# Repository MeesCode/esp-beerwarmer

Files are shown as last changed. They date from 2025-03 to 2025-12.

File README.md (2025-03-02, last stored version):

# ESP32-H2 Demo Zigbee Device

This project is a demo Zigbee device based on the ESP32-H2 / ESP32-C6

## Features

- [x] DHT22 temperature and humidity sensor
- [x] Binary switch
- [x] Binary input

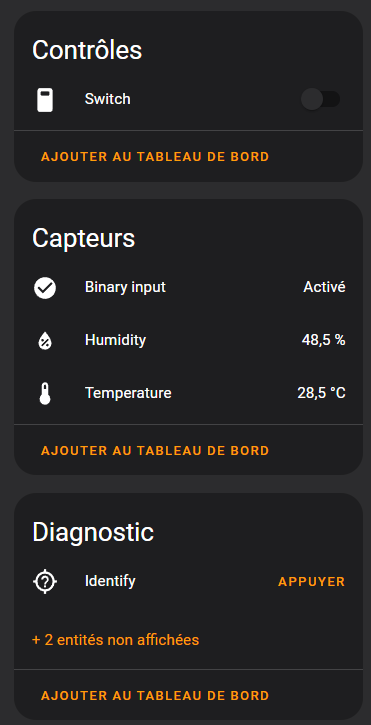
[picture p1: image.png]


## Hardware

- [ESP32-H2](https://www.espressif.com/en/products/socs/h2/overview)

## GPIO

| GPIO | Function |
| --- | --- |
| GPIO8  | DHT22 data |
| GPIO0  | Binary output (LED) |
| GPIO12 | Binary input (Button) |

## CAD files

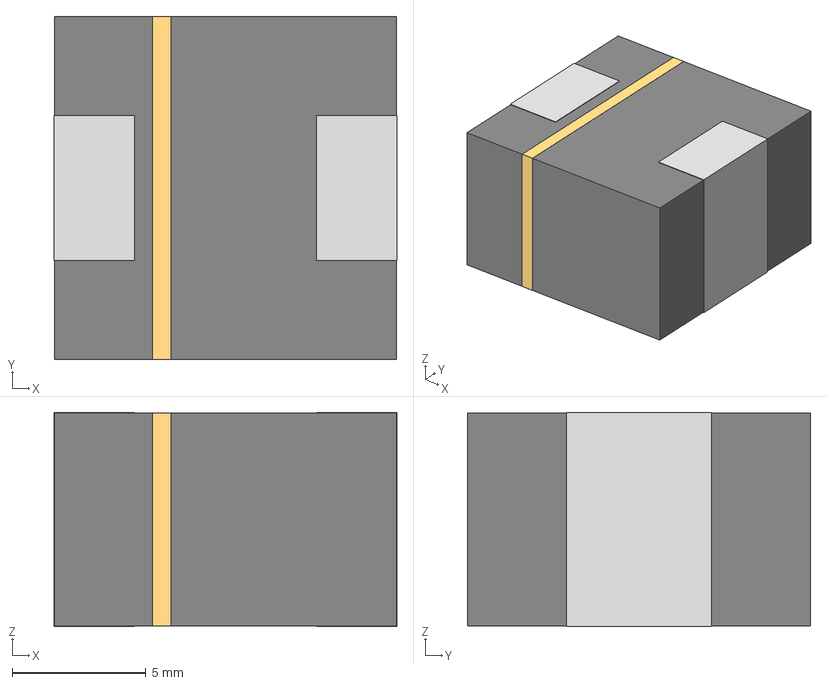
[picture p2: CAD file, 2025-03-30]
beer-warmer-schematics/3d models/IND_BOURNS_SRR1280.step
12.8 x 12.8 x 8.00 mm

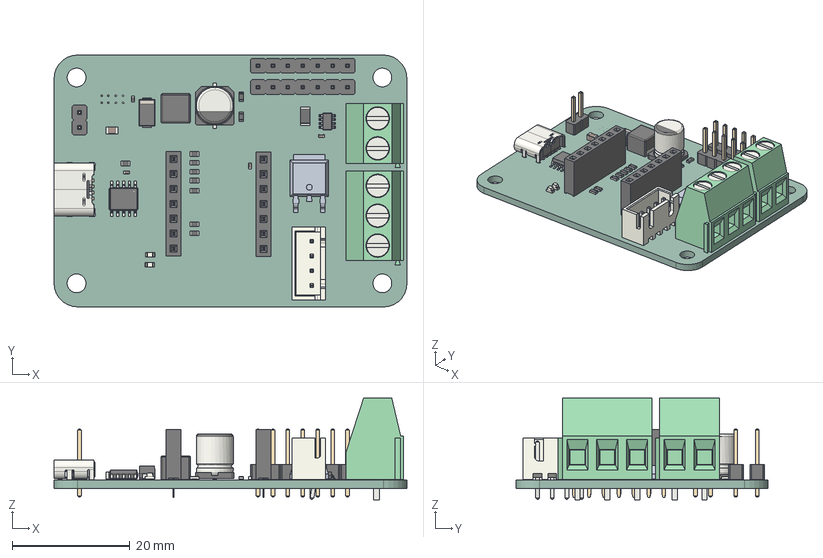
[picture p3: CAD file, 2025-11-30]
beer-warmer-schematics/beer-warmer-schematics.step
60.0 x 42.8 x 17.3 mm
C_0402_1005Metric x 4
LED_0603_1608Metric x 2
R_0603_1608Metric x 10
PinHeader_1x07_P2.54mm_Vertical x 2
R_1206_3216Metric
JST_XH_B4B-XH-A_1x04_P2.50mm_Vertical
TerminalBlock_Phoenix_MKDS-1,5-2-5.08_1x02_P5.08mm_Horizontal
beer-warmer-schematics 1.9.1
USB_C_Receptacle_GCT_USB4125-xx-x_6P_TopMnt_Horizontal
SOT-23-8
CP_Elec_6.3x7.7
PinHeader_1x02_P2.54mm_Vertical
C_0805_2012Metric
L_Changjiang_FNR5040S
D_SMA
TerminalBlock_Phoenix_MKDS-1,5-3-5.08_1x03_P5.08mm_Horizontal
PinSocket_1x07_P2.54mm_Vertical x 2
SSOP-10-1EP_3.9x4.9mm_P1mm_EP2.1x3.3mm
beer-warmer-schematics_PCB

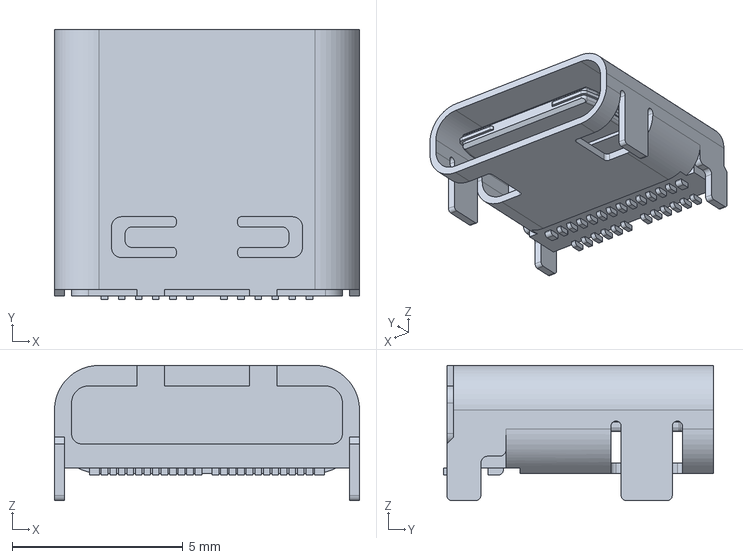
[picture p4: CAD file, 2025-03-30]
beer-warmer-schematics/3d models/1054500101.stp
8.94 x 7.90 x 3.96 mm

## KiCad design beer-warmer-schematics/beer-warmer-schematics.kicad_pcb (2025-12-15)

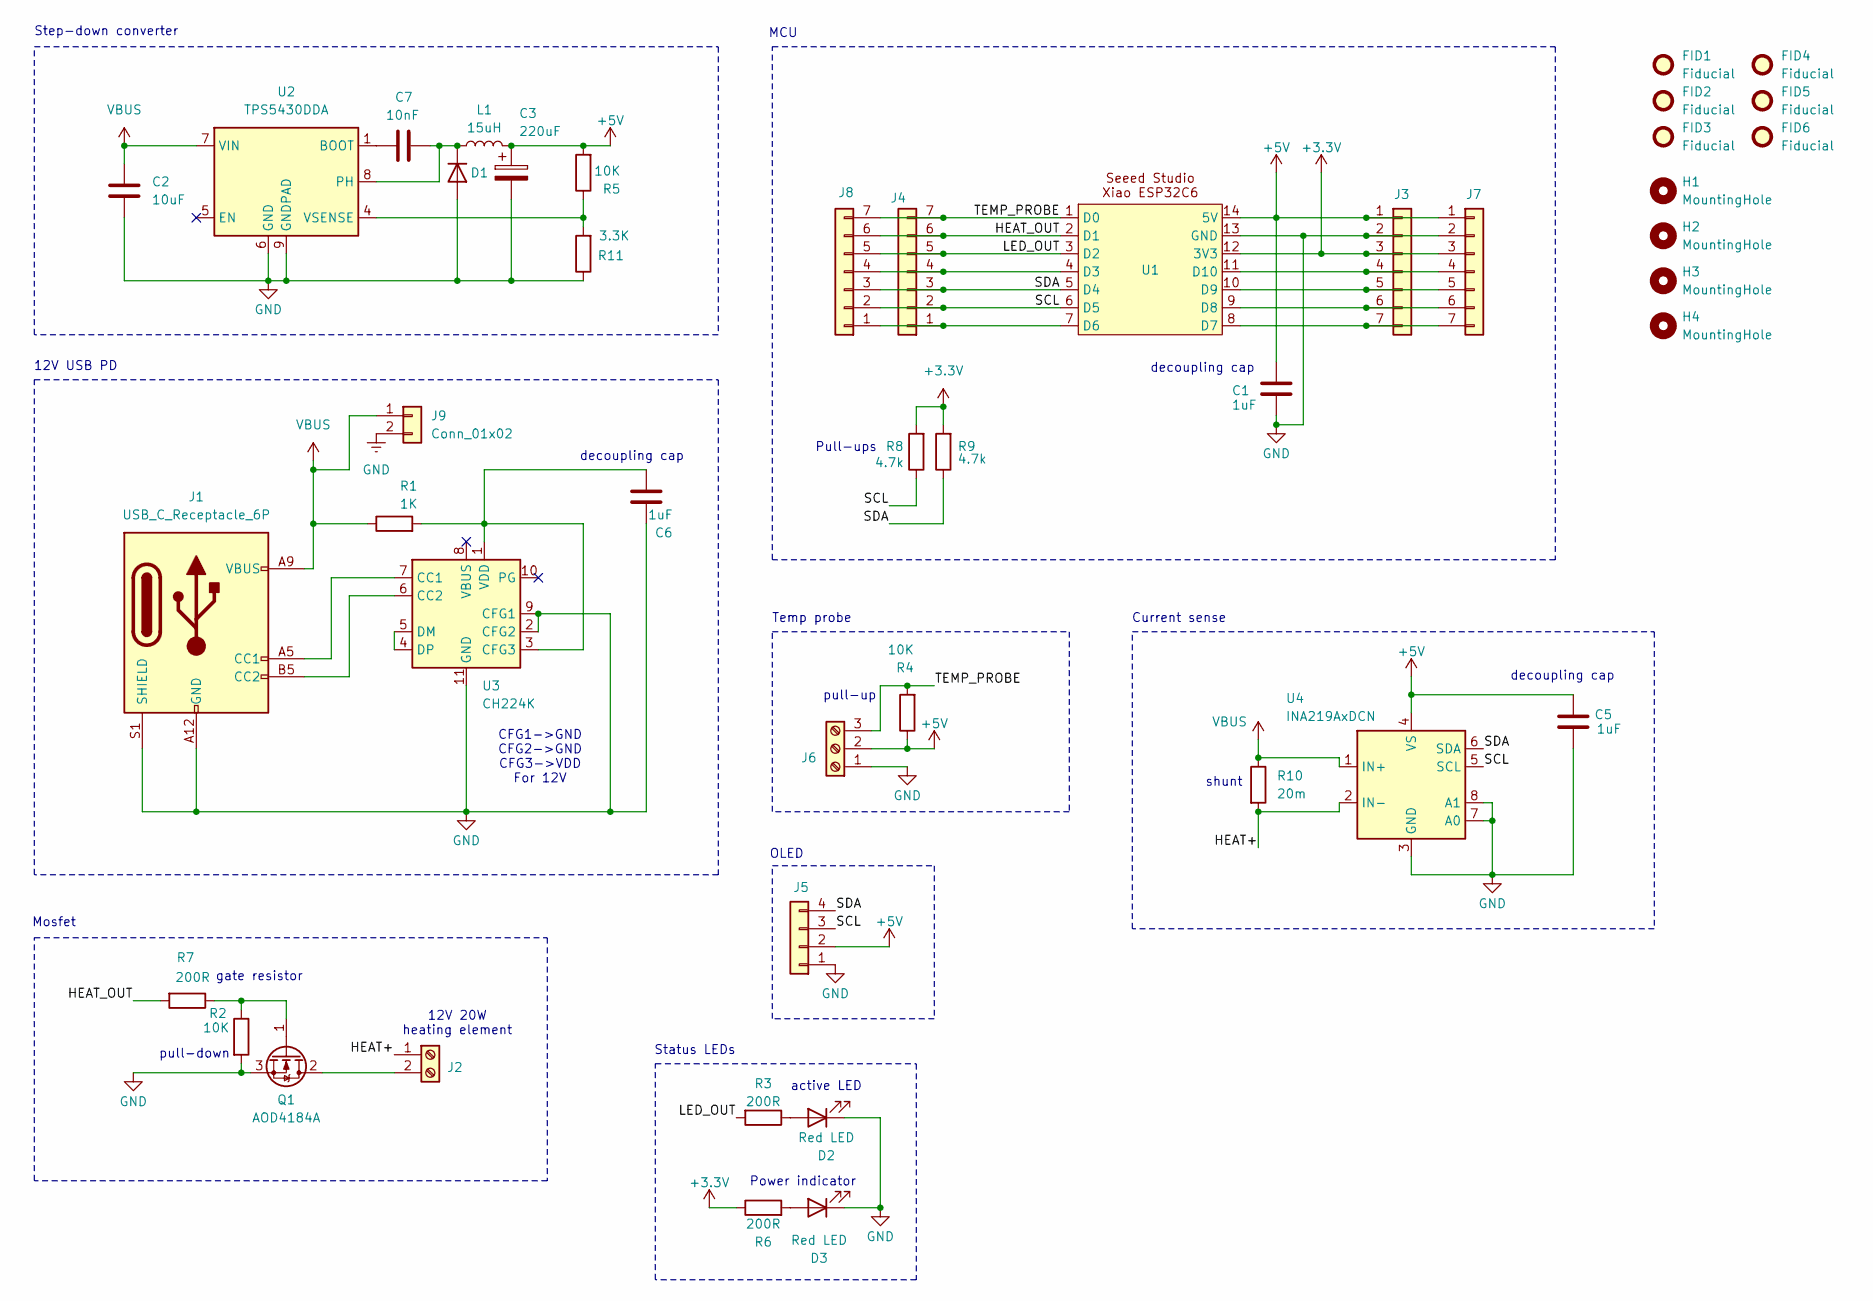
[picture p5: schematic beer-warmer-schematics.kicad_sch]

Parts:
C1, C5, C6: 1uF; C_0402_1005Metric; LCSC C52923
C2: 10uF; C_0805_2012Metric; LCSC C15850
C3: 220uF; CP_Elec_6.3x7.7; LCSC C3342
C7: 10nF; C_0402_1005Metric; LCSC C1524
D1: D; D_SMA; Manufacturer # B530C-13-F; LCSC C64982
D2, D3: Red LED; LED_0603_1608Metric; LCSC C2286
FID1, FID2, FID3, FID4, FID5, FID6: Fiducial; Fiducial_0.5mm_Mask1.5mm
H1, H2, H3, H4: MountingHole; MountingHole_3.2mm_M3_DIN965_Pad
J1: USB_C_Receptacle_6P; USB_C_Receptacle_GCT_USB4125-xx-x_6P_TopMnt_Horizontal; Manufacturer # 1054500101; LCSC C456012
J2: Screw_Terminal_01x02; TerminalBlock_Phoenix_MKDS-1,5-2-5.08_1x02_P5.08mm_Horizont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; LCSC C8465
J3, J4: Conn_01x07_Socket; PinSocket_1x07_P2.54mm_Vertical; LCSC C2932672
J5: Conn_01x04_Pin; JST_XH_B4B-XH-A_1x04_P2.50mm_Vertical; LCSC C594232
J6: Screw_Terminal_01x03; TerminalBlock_Phoenix_MKDS-1,5-3-5.08_1x03_P5.08mm_Horizont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; LCSC C72334
J7, J8: Conn_01x07_Socket; PinHeader_1x07_P2.54mm_Vertical; LCSC C2932672
J9: Conn_01x02; PinHeader_1x02_P2.54mm_Vertical
L1: 15uH; L_Changjiang_FNR5040S; LCSC C167969
Q1: AOD4184A; TO-252-2; LCSC C99124
R1: 1K; R_0603_1608Metric; LCSC C21190
R2, R4, R5: 10K; R_0603_1608Metric; LCSC C15401
R3, R6, R7: 200R; R_0603_1608Metric; LCSC C22962
R8, R9: 4.7k; R_0603_1608Metric; LCSC C23162
R10: 20m; R_1206_3216Metric; LCSC C393094
R11: 3.3K; R_0603_1608Metric; LCSC C22978
U1: XIAO-ESP32C6-DIP
U2: TPS5430DDA; TI_SO-PowerPAD-8_ThermalVias; LCSC C9864
U3: CH224K; SSOP-10-1EP_3.9x4.9mm_P1mm_EP2.1x3.3mm; LCSC C970725
U4: INA219AxDCN; SOT-23-8; LCSC C87469

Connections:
+3.3V: J3.3, J7.3, R6.1, R8.2, R9.2, U1.12 (3V3)
+5V: C1.1, C3.1, C5.2, J3.1, J5.2, J6.2, J7.1, L1.2, R4.1, R5.2, U1.14 (5V), U4.4 (VS); also elsewhere on the board
/<NO NET>: J4.4, J8.4, U1.4 (D3)
/HEAT+: J2.1, R10.2, U4.2 (IN-)
/HEAT_OUT: J4.6, J8.6, R7.2, U1.2 (D1)
/LED_OUT: J4.5, J8.5, R3.2, U1.3 (D2)
/SCL: J4.2, J5.3, J8.2, R8.1, U1.6 (D5), U4.5 (SCL)
/SDA: J4.3, J5.4, J8.3, R9.1, U1.5 (D4), U4.6 (SDA)
/TEMP_PROBE: J4.7, J6.3, J8.7, R4.2, U1.1 (D0)
GND: C1.2, C2.2, C3.2, C5.1, C6.1, D1.2 (A), D2.1 (K), D3.1 (K), J1.A12 (GND), J1.B12 (GND), J1.S1 (SHIELD), J3.2, J5.1, J6.1, J7.2, J9.2, Q1.3 (S), R2.2, R11.1, U1.13 (GND), U2.6 (GND), U2.9 (GNDPAD), U3.2 (CFG2), U3.9 (CFG1), U3.11 (GND), U4.3 (GND), U4.7 (A0), U4.8 (A1)
unnamed: C7.1, D1.1 (K), L1.1, U2.8 (PH)
unnamed: D2.2 (A), R3.1
unnamed: D3.2 (A), R6.2
unnamed: J1.A5 (CC1), U3.7 (CC1)
unnamed: J1.B5 (CC2), U3.6 (CC2)
unnamed: J2.2, Q1.2 (D)
unnamed: J3.4, J7.4, U1.11 (D10)
unnamed: J3.5, J7.5, U1.10 (D9)
unnamed: J3.6, J7.6, U1.9 (D8)
unnamed: J3.7, J7.7, U1.8 (D7)
unnamed: J4.1, J8.1, U1.7 (D6)
unnamed: Q1.1 (G), R2.1, R7.1
unnamed: C7.2, U2.1 (BOOT)
unnamed: R5.1, R11.2, U2.4 (VSENSE)
unnamed: C6.2, R1.2, U3.1 (VDD), U3.3 (CFG3)
unnamed: U3.4 (DP), U3.5 (DM)
VBUS: C2.1, J1.A9 (VBUS), J1.B9 (VBUS), J9.1, R1.1, R10.1, U2.7 (VIN), U4.1 (IN+)

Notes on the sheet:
decoupling cap
12V 20W heating element
12V USB PD
Status LEDs
Current sense
OLED
pull-up
Power indicator
gate resistor
shunt
active LED
Step-down converter
Mosfet
Pull-ups
pull-down
CFG1->GND CFG2->GND CFG3->VDD For 12V
MCU
Temp probe

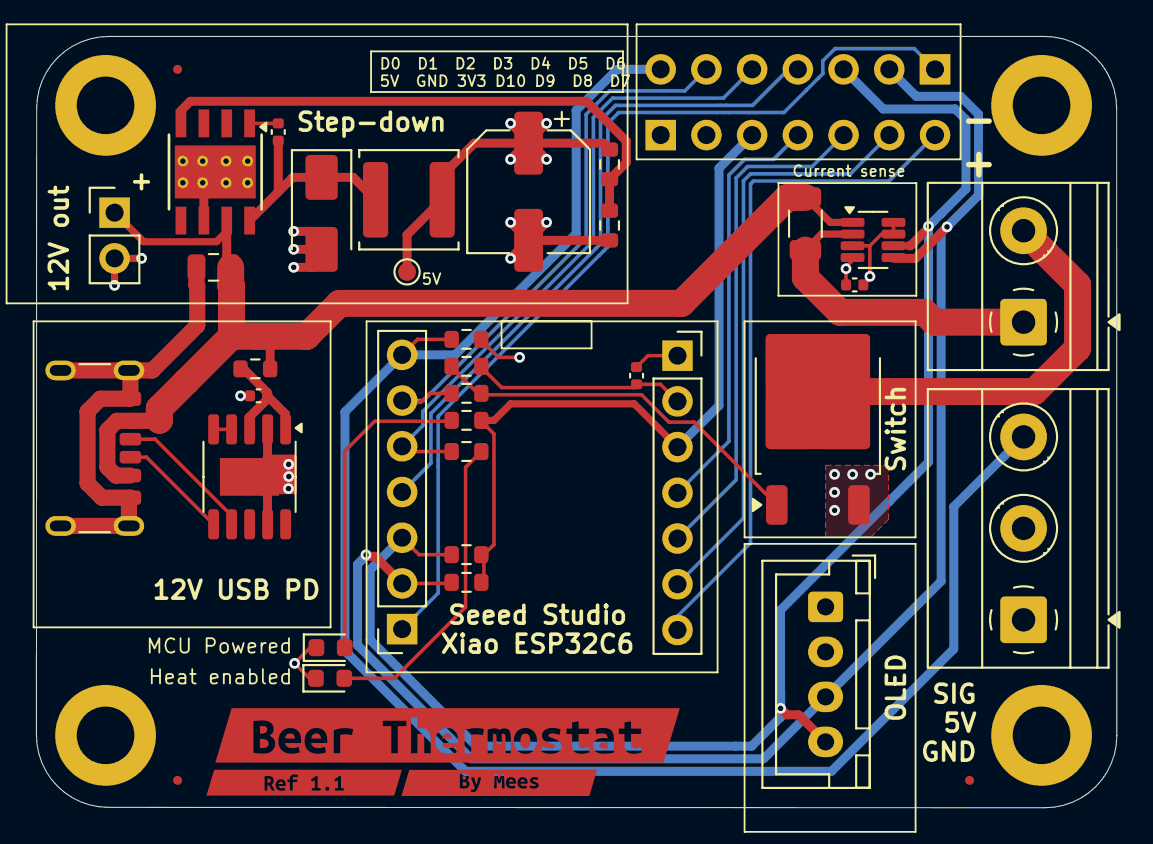
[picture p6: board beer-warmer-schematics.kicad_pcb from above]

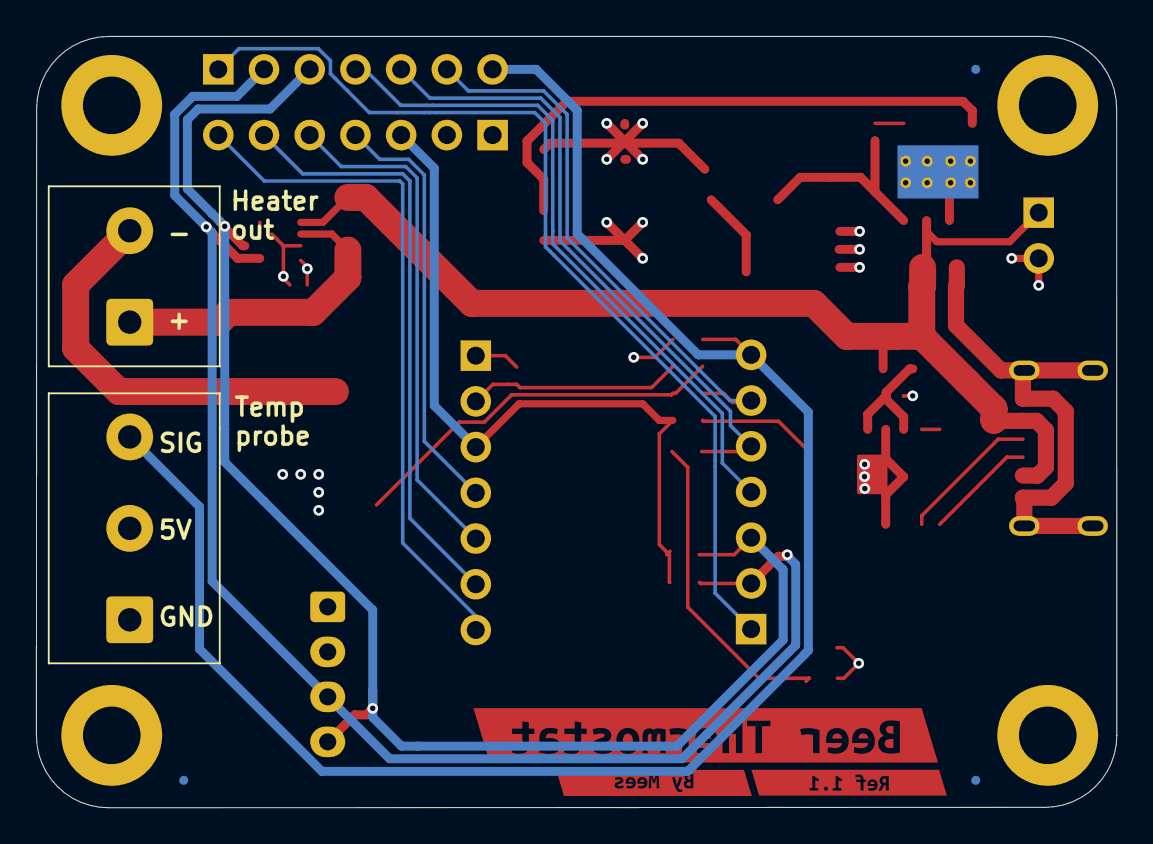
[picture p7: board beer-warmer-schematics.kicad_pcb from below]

Board: 4 copper layers, 60.0 x 42.8 mm, 48 parts (3 on the bottom side), 27 nets.

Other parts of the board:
TP2: TestPoint; TestPoint_Pad_D1.0mm
kibuzzard-67EFB7C2: G***; kibuzzard-67EFB7C2
kibuzzard-67EFB7D4: G***; kibuzzard-67EFB7D4
kibuzzard-693FEE7D: G***; kibuzzard-693FEE7D

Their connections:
+5V: TP2.1; also elsewhere on the board

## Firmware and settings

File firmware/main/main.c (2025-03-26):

#include "nvs_flash.h"
#include "esp_check.h"
#include "esp_log.h"
#include "freertos/FreeRTOS.h"
#include "freertos/task.h"
#include "ha/esp_zigbee_ha_standard.h"
#include "main.h"
#include "string.h"
#include "driver/gpio.h"
#include "temp_sensor.h"

#include "driver/i2c_master.h"
#include "esp_lcd_panel_io.h"
#include "esp_lcd_panel_vendor.h"
#include "esp_lcd_panel_ops.h"

#include "oled_gfx.h"

#define HEATER_PIN GPIO_NUM_1

static const char *TAG = "MAIN";
bool zb_connected = false;
bool switch_state = true;

const float target_temp = 22.0;
const float temp_offset = 0.1;

float temps[128] = {-1.0f};
int temp_index = 0;

#define DEFINE_PSTRING(var, str)   \
    const struct                   \
    {                              \
        unsigned char len;         \
        char content[sizeof(str)]; \
    }(var) = {sizeof(str) - 1, (str)}


void report_output_binary_sensor(uint16_t value)
{
    esp_zb_zcl_set_attribute_val(
        HA_ESP_ENDPOINT,
        ESP_ZB_ZCL_CLUSTER_ID_BINARY_INPUT, 
        ESP_ZB_ZCL_CLUSTER_SERVER_ROLE, 
        ESP_ZB_ZCL_ATTR_BINARY_INPUT_PRESENT_VALUE_ID, 
        &value, 
        false
    );
}

void report_temperature(float temp)
{
    uint16_t temp_zb = (uint16_t)(temp*100.);
    esp_zb_zcl_set_attribute_val(
        HA_ESP_ENDPOINT, 
        ESP_ZB_ZCL_CLUSTER_ID_TEMP_MEASUREMENT, 
        ESP_ZB_ZCL_CLUSTER_SERVER_ROLE, 
        ESP_ZB_ZCL_ATTR_TEMP_MEASUREMENT_VALUE_ID, 
        &temp_zb, 
        false
    );
}

void draw_graph()
{
    gfx_clear_area(0, 32, 128, 32);
    float max_temp = 0;
    float min_temp = 100;
    for(int i = 0; i < 128; i++){
        if(temps[i] > max_temp && temps[i] >= 0) max_temp = temps[i] + 0.5;
        if(temps[i] < min_temp && temps[i] >= 0) min_temp = temps[i] - 0.5;
    }

    float pxpt = (32.0) / (max_temp - min_temp);
    ESP_LOGI(TAG, "index: %d, max_temp: %f, min_temp: %f", temp_index, max_temp, min_temp);

    int prev_y = -1.0f;
    for(int i = 0; i < 128; i++){
        int index = (temp_index + i + 1) % 128;

        if(temps[index] < 0) continue;
        int y = pxpt * (temps[index] - min_temp);

        if(prev_y < 0){
            gfx_set_pixel(i, 64 - y);
        } else if(y > prev_y){
            gfx_fill_area(i, 64 - y, 1, y - prev_y);
        } else if(y < prev_y){
            gfx_fill_area(i, 64 - prev_y, 1, prev_y - y);
        } else {
            gfx_set_pixel(i, 64 - y);
        }

        prev_y = y;
    }
    
}

static void temp_task(void *pvParameters)
{
    for(;;){
        vTaskDelay(100 / portTICK_PERIOD_MS);

        float temp = get_temp();

        char temp_str[10];
        sprintf(temp_str, "%.2f C ", temp);
        gfx_draw_text(0, 10, temp_str);

        temps[temp_index] = temp;

        draw_graph();
        if(zb_connected)
            report_temperature(temp);

        // roughly keep temp at 25c by turning on/off the heater
        if(temp < target_temp - temp_offset && switch_state){
            gpio_set_level(HEATER_PIN, 1);
            if(zb_connected)
                report_output_binary_sensor(1);
            gfx_draw_text(0, 20, "heat on ");
        } else if(temp > target_temp + temp_offset || !switch_state){
            gpio_set_level(HEATER_PIN, 0);
            if(zb_connected)
                report_output_binary_sensor(0);
            gfx_draw_text(0, 20, "heat off");
        }

        gfx_flush();
        temp_index = (temp_index + 1) % 128;
    }
}

static void bdb_start_top_level_commissioning_cb(uint8_t mode_mask)
{
    ESP_ERROR_CHECK(esp_zb_bdb_start_top_level_commissioning(mode_mask));
}

static esp_err_t zb_attribute_handler(const esp_zb_zcl_set_attr_value_message_t *message)
{
    esp_err_t ret = ESP_OK;
    ESP_RETURN_ON_FALSE(message, ESP_FAIL, TAG, "Empty message");
    ESP_RETURN_ON_FALSE(message->info.status == ESP_ZB_ZCL_STATUS_SUCCESS, ESP_ERR_INVALID_ARG, TAG, "Received message: error status(%d)",
                        message->info.status);
    ESP_LOGI(TAG, "Received message: endpoint(0x%x), cluster(0x%x), attribute(0x%x), data size(%d)", message->info.dst_endpoint, message->info.cluster, message->attribute.id, message->attribute.data.size);

    // handle light on/off
    if (message->info.dst_endpoint == HA_ESP_ENDPOINT){
        if (message->info.cluster == ESP_ZB_ZCL_CLUSTER_ID_ON_OFF){
            if (message->attribute.id == ESP_ZB_ZCL_ATTR_ON_OFF_ON_OFF_ID && message->attribute.data.type == ESP_ZB_ZCL_ATTR_TYPE_BOOL){
                switch_state = message->attribute.data.value ? *(bool *)message->attribute.data.value : switch_state;
                gpio_set_level(GPIO_NUM_15, !switch_state);
                ESP_LOGI(TAG, "Light sets to %s", switch_state ? "On" : "Off");
            }
        }
    }
    
    return ret;
}

static esp_err_t zb_action_handler(esp_zb_core_action_callback_id_t callback_id, const void *message)
{
    esp_err_t ret = ESP_OK;
    switch (callback_id)
    {
    case ESP_ZB_CORE_SET_ATTR_VALUE_CB_ID:
        ret = zb_attribute_handler((esp_zb_zcl_set_attr_value_message_t *)message);
        break;
    default:
        ESP_LOGW(TAG, "Receive Zigbee action(0x%x) callback", callback_id);
        break;
    }
    return ret;
}

void esp_zb_app_signal_handler(esp_zb_app_signal_t *signal_struct)
{
    uint32_t *p_sg_p = signal_struct->p_app_signal;
    esp_err_t err_status = signal_struct->esp_err_status;
    esp_zb_app_signal_type_t sig_type = *p_sg_p;
    switch (sig_type) {
    case ESP_ZB_ZDO_SIGNAL_SKIP_STARTUP:
        ESP_LOGI(TAG, "Initialize Zigbee stack");
        esp_zb_bdb_start_top_level_commissioning(ESP_ZB_BDB_MODE_INITIALIZATION);
        break;
    case ESP_ZB_BDB_SIGNAL_DEVICE_FIRST_START:
    case ESP_ZB_BDB_SIGNAL_DEVICE_REBOOT:
        if (err_status == ESP_OK) {
            ESP_LOGI(TAG, "Device started up in%s factory-reset mode", esp_zb_bdb_is_factory_new() ? "" : " non");
            if (esp_zb_bdb_is_factory_new()) {
                ESP_LOGI(TAG, "Start network steering");
                esp_zb_bdb_start_top_level_commissioning(ESP_ZB_BDB_MODE_NETWORK_STEERING);
            } else {
                ESP_LOGI(TAG, "Device connected");
                zb_connected = true;
                gfx_draw_text(112, 0, "zb");
            }
        } else {
            ESP_LOGW(TAG, "%s failed with status: %s, retrying", esp_zb_zdo_signal_to_string(sig_type), esp_err_to_name(err_status));
            esp_zb_scheduler_alarm((esp_zb_callback_t)bdb_start_top_level_commissioning_cb,
                                   ESP_ZB_BDB_MODE_INITIALIZATION, 1000);
        }
        break;
    case ESP_ZB_BDB_SIGNAL_STEERING:
        if (err_status == ESP_OK) {
            esp_zb_ieee_addr_t extended_pan_id;
            esp_zb_get_extended_pan_id(extended_pan_id);
            ESP_LOGI(TAG, "Joined network successfully (Extended PAN ID: %02x:%02x:%02x:%02x:%02x:%02x:%02x:%02x, PAN ID: 0x%04hx, Channel:%d, Short Address: 0x%04hx)",
                     extended_pan_id[7], extended_pan_id[6], extended_pan_id[5], extended_pan_id[4],
                     extended_pan_id[3], extended_pan_id[2], extended_pan_id[1], extended_pan_id[0],
                     esp_zb_get_pan_id(), esp_zb_get_current_channel(), esp_zb_get_short_address());
            zb_connected = true;
            gfx_draw_text(112, 0, "zb");
        } else {
            ESP_LOGI(TAG, "Network steering was not successful (status: %s)", esp_err_to_name(err_status));
            esp_zb_scheduler_alarm((esp_zb_callback_t)bdb_start_top_level_commissioning_cb, ESP_ZB_BDB_MODE_NETWORK_STEERING, 1000);
        }
        break;
    default:
        ESP_LOGI(TAG, "ZDO signal: %s (0x%x), status: %s", esp_zb_zdo_signal_to_string(sig_type), sig_type, esp_err_to_name(err_status));
        break;
    }
}

static void esp_zb_task(void *pvParameters)
{
    // setup zigbee
    esp_zb_cfg_t zb_nwk_cfg = ESP_ZB_ZED_CONFIG();
    esp_zb_init(&zb_nwk_cfg);

    // setup basic cluster
    esp_zb_basic_cluster_cfg_t basic_cluster_cfg = {
        .zcl_version = ESP_ZB_ZCL_BASIC_ZCL_VERSION_DEFAULT_VALUE,
        .power_source = 0x03,
    };
    uint32_t ApplicationVersion = 0x0001;
    uint32_t StackVersion = 0x0002;
    uint32_t HWVersion = 0x0002;
    DEFINE_PSTRING(ManufacturerName, "Seed Studio");
    DEFINE_PSTRING(ModelIdentifier, "Beer warmer");
    DEFINE_PSTRING(DateCode, "20250303");

    esp_zb_attribute_list_t *esp_zb_basic_cluster = esp_zb_basic_cluster_create(&basic_cluster_cfg);
    esp_zb_basic_cluster_add_attr(esp_zb_basic_cluster, ESP_ZB_ZCL_ATTR_BASIC_APPLICATION_VERSION_ID, &ApplicationVersion);
    esp_zb_basic_cluster_add_attr(esp_zb_basic_cluster, ESP_ZB_ZCL_ATTR_BASIC_STACK_VERSION_ID, &StackVersion);
    esp_zb_basic_cluster_add_attr(esp_zb_basic_cluster, ESP_ZB_ZCL_ATTR_BASIC_HW_VERSION_ID, &HWVersion);
    esp_zb_basic_cluster_add_attr(esp_zb_basic_cluster, ESP_ZB_ZCL_ATTR_BASIC_MANUFACTURER_NAME_ID, (void *)&ManufacturerName);
    esp_zb_basic_cluster_add_attr(esp_zb_basic_cluster, ESP_ZB_ZCL_ATTR_BASIC_MODEL_IDENTIFIER_ID, (void *)&ModelIdentifier);
    esp_zb_basic_cluster_add_attr(esp_zb_basic_cluster, ESP_ZB_ZCL_ATTR_BASIC_DATE_CODE_ID, (void *)&DateCode);

    // cluster identify
    esp_zb_identify_cluster_cfg_t identify_cluster_cfg = {
        .identify_time = 0,
    };
    esp_zb_attribute_list_t *esp_zb_identify_cluster = esp_zb_identify_cluster_create(&identify_cluster_cfg);

    // cluster light
    esp_zb_on_off_cluster_cfg_t on_off_cfg = {
        .on_off = 0,
    };
    esp_zb_attribute_list_t *esp_zb_on_off_cluster = esp_zb_on_off_cluster_create(&on_off_cfg);

    // cluster temperature measurement (0 to 30 degree celsius)
    esp_zb_temperature_meas_cluster_cfg_t temperature_meas_cfg = {
        .measured_value = 0xFFFF,
        .min_value = 0,
        .max_value = 5000,
    };
    esp_zb_attribute_list_t *esp_zb_temperature_meas_cluster = esp_zb_temperature_meas_cluster_create(&temperature_meas_cfg);

    // cluster binary sensor
    esp_zb_binary_input_cluster_cfg_t binary_input_cfg = {
        .out_of_service = false,
        .status_flags = 0,
        .present_value = 0,
    };
    esp_zb_attribute_list_t *esp_zb_binary_input_cluster = esp_zb_binary_input_cluster_create(&binary_input_cfg);

    // create cluster list
    esp_zb_cluster_list_t *esp_zb_cluster_list = esp_zb_zcl_cluster_list_create();
    esp_zb_cluster_list_add_basic_cluster(esp_zb_cluster_list, esp_zb_basic_cluster, ESP_ZB_ZCL_CLUSTER_SERVER_ROLE);
    esp_zb_cluster_list_add_identify_cluster(esp_zb_cluster_list, esp_zb_identify_cluster, ESP_ZB_ZCL_CLUSTER_SERVER_ROLE);
    esp_zb_cluster_list_add_on_off_cluster(esp_zb_cluster_list, esp_zb_on_off_cluster, ESP_ZB_ZCL_CLUSTER_SERVER_ROLE);
    esp_zb_cluster_list_add_temperature_meas_cluster(esp_zb_cluster_list, esp_zb_temperature_meas_cluster, ESP_ZB_ZCL_CLUSTER_SERVER_ROLE);
    esp_zb_cluster_list_add_binary_input_cluster(esp_zb_cluster_list, esp_zb_binary_input_cluster, ESP_ZB_ZCL_CLUSTER_SERVER_ROLE);

    // create endpoint list
    esp_zb_ep_list_t *esp_zb_ep_list = esp_zb_ep_list_create();
    esp_zb_endpoint_config_t endpoint_config = {
        .endpoint = HA_ESP_ENDPOINT,
        .app_profile_id = ESP_ZB_AF_HA_PROFILE_ID,
        .app_device_id = ESP_ZB_HA_ON_OFF_LIGHT_DEVICE_ID,
    };
    esp_zb_ep_list_add_ep(esp_zb_ep_list, esp_zb_cluster_list, endpoint_config);

    // Register device
    esp_zb_device_register(esp_zb_ep_list);
    esp_zb_core_action_handler_register(zb_action_handler);

    esp_zb_zcl_reporting_info_t reporting_info = {
        .direction = ESP_ZB_ZCL_CMD_DIRECTION_TO_SRV,
        .ep = HA_ESP_ENDPOINT,
        .cluster_id = ESP_ZB_ZCL_CLUSTER_ID_TEMP_MEASUREMENT,
        .cluster_role = ESP_ZB_ZCL_CLUSTER_SERVER_ROLE,
        .dst.profile_id = ESP_ZB_AF_HA_PROFILE_ID,
        .u.send_info.min_interval = 1,
        .u.send_info.max_interval = 0,
        .u.send_info.def_min_interval = 1,
        .u.send_info.def_max_interval = 0,
        .u.send_info.delta.u16 = 1,
        .attr_id = ESP_ZB_ZCL_ATTR_TEMP_MEASUREMENT_VALUE_ID,
        .manuf_code = ESP_ZB_ZCL_ATTR_NON_MANUFACTURER_SPECIFIC,
    };
    esp_zb_zcl_update_reporting_info(&reporting_info);

    // setup automatic reporting for binary input
    esp_zb_zcl_reporting_info_t reporting_info_binary = {
        .direction = ESP_ZB_ZCL_CMD_DIRECTION_TO_SRV,
        .ep = HA_ESP_ENDPOINT,
        .cluster_id = ESP_ZB_ZCL_CLUSTER_ID_BINARY_INPUT,
        .cluster_role = ESP_ZB_ZCL_CLUSTER_SERVER_ROLE,
        .dst.profile_id = ESP_ZB_AF_HA_PROFILE_ID,
        .u.send_info.min_interval = 1,
        .u.send_info.max_interval = 0,
        .u.send_info.def_min_interval = 1,
        .u.send_info.def_max_interval = 0,
        .u.send_info.delta.u8 = 1,
        .u.send_info.reported_value.u8 = 0,
        .attr_id = ESP_ZB_ZCL_ATTR_BINARY_INPUT_PRESENT_VALUE_ID,
        .manuf_code = ESP_ZB_ZCL_ATTR_NON_MANUFACTURER_SPECIFIC,
    };
    esp_zb_zcl_update_reporting_info(&reporting_info_binary);

    // start zigbee
    esp_zb_set_primary_network_channel_set(ESP_ZB_PRIMARY_CHANNEL_MASK);
    ESP_ERROR_CHECK(esp_zb_start(false));
    esp_zb_stack_main_loop();
}

void app_main(void)
{
    // setup onboard led
    gpio_set_direction(GPIO_NUM_15, GPIO_MODE_OUTPUT);
    gpio_set_level(GPIO_NUM_15, 0);

    // setup heater gpio
    gpio_set_direction(HEATER_PIN, GPIO_MODE_OUTPUT);
    gpio_set_level(HEATER_PIN, 0);

    // setup temperature sensor
    for(int i = 0; i < 128; i++){
        temps[i] = -1.0f;
    }
    init_temp_sensor();

    // use internal antenna
    gpio_set_direction(GPIO_NUM_3, GPIO_MODE_OUTPUT);
    gpio_set_level(GPIO_NUM_3, 0);
    gpio_set_direction(GPIO_NUM_14, GPIO_MODE_OUTPUT);
    gpio_set_level(GPIO_NUM_14, 0);

    // setup zigbee
    esp_zb_platform_config_t config = {
        .radio_config = ESP_ZB_DEFAULT_RADIO_CONFIG(),
        .host_config = ESP_ZB_DEFAULT_HOST_CONFIG(),
    };
    ESP_ERROR_CHECK(nvs_flash_init());
    ESP_ERROR_CHECK(esp_zb_platform_config(&config));

    i2c_master_bus_config_t i2c_bus_conf = {
        .clk_source = I2C_CLK_SRC_DEFAULT,
        .sda_io_num = TEST_I2C_SDA_GPIO,
        .scl_io_num = TEST_I2C_SCL_GPIO,
        .i2c_port = I2C_NUM_0,
        .flags.enable_internal_pullup = true,
    };

    i2c_master_bus_handle_t bus_handle;
    i2c_new_master_bus(&i2c_bus_conf, &bus_handle);

    esp_lcd_panel_io_handle_t io_handle = NULL;
    esp_lcd_panel_io_i2c_config_t io_config = {
        .dev_addr = TEST_I2C_DEV_ADDR,
        .scl_speed_hz = TEST_LCD_PIXEL_CLOCK_HZ,
        .control_phase_bytes = 1, // According to SSD1306 datasheet
        .dc_bit_offset = 6,       // According to SSD1306 datasheet
        .lcd_cmd_bits = 8,        // According to SSD1306 datasheet
        .lcd_param_bits = 8,      // According to SSD1306 datasheet
    };

    esp_lcd_new_panel_io_i2c(bus_handle, &io_config, &io_handle);

    esp_lcd_panel_handle_t panel_handle = NULL;
    esp_lcd_panel_dev_config_t panel_config = {
        .bits_per_pixel = 1,
        .reset_gpio_num = -1,
    };
    esp_lcd_new_panel_ssd1306(io_handle, &panel_config, &panel_handle);
    esp_lcd_panel_reset(panel_handle);
    esp_lcd_panel_init(panel_handle);
    // turn on display
    esp_lcd_panel_disp_on_off(panel_handle, true);

    // mirror the display
    esp_lcd_panel_mirror(panel_handle, true, true);

    

    gfx_init(panel_handle, TEST_LCD_H_RES, TEST_LCD_V_RES);

    gfx_clear_area(0, 0, 128, 64);
    gfx_draw_text(0, 0, "Beer warmer");
    gfx_flush();

    // while(1){

    //     temps[temp_index] = temp_index > 0 ? temps[(temp_index - 1) % 128] + ((rand() % 2) - 0.5) : temps[119] + ((rand() % 2) - 0.5);

    //     char temp_str[10];
    //     sprintf(temp_str, "%.2f C ", temps[temp_index]);
    //     gfx_draw_text(0, 10, temp_str);

    //     draw_graph();
    //     gfx_flush();

    //     temp_index = (temp_index + 1) % 128;
    // }

    // task for keeping track of temperature
    xTaskCreate(temp_task, "temp_task", 4096, NULL, 5, NULL);

    // task for zigbee
    xTaskCreate(esp_zb_task, "Zigbee_main", 4096, NULL, 5, NULL);
}

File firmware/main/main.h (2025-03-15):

#include "esp_zigbee_core.h"

/* Zigbee configuration */
#define INSTALLCODE_POLICY_ENABLE false
#define ED_AGING_TIMEOUT ESP_ZB_ED_AGING_TIMEOUT_64MIN
#define ED_KEEP_ALIVE 3000
#define HA_ESP_ENDPOINT 10
#define ESP_ZB_PRIMARY_CHANNEL_MASK ESP_ZB_TRANSCEIVER_ALL_CHANNELS_MASK 

#define ESP_ZB_ZED_CONFIG()                               \
    {                                                     \
        .esp_zb_role = ESP_ZB_DEVICE_TYPE_ED,             \
        .install_code_policy = INSTALLCODE_POLICY_ENABLE, \
        .nwk_cfg.zed_cfg = {                              \
            .ed_timeout = ED_AGING_TIMEOUT,               \
            .keep_alive = ED_KEEP_ALIVE,                  \
        },                                                \
    }

#define ESP_ZB_DEFAULT_RADIO_CONFIG()    \
    {                                    \
        .radio_mode = ZB_RADIO_MODE_NATIVE, \
    }

#define ESP_ZB_DEFAULT_HOST_CONFIG()                       \
    {                                                      \
        .host_connection_mode = ZB_HOST_CONNECTION_MODE_NONE, \
    }


#define TEST_LCD_V_RES          64
#define TEST_LCD_H_RES          128

#define TEST_I2C_SDA_GPIO       22
#define TEST_I2C_SCL_GPIO       23

#define TEST_I2C_DEV_ADDR       0x3C

#define TEST_LCD_PIXEL_CLOCK_HZ (400 * 1000)

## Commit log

2025-03-03 fix antenna
2025-03-03 cleanup and remove build files
    [partitions.csv]
2025-03-03 add required files
    [partitions.csv]
2025-03-03 cleanup, fix led gpio direction
    [esp_zb_light.c]
2025-03-05 temp sensor working
2025-03-05 very basic temperature control
2025-03-05 cleanup and add binary output for heater
2025-03-05 fix some reporting issues
    [main.c]
2025-03-30 add schematics
    [1054500101.stp, beer-warmer-schematics.kicad_pcb, beer-warmer-schematics.kicad_sch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]
2025-03-30 initial routing
    [IND_BOURNS_SRR1280.step, beer-warmer-schematics.kicad_pcb, beer-warmer-schematics.kicad_sch]
2025-03-30 cleanup add more lcsc numbers
    [beer-warmer-schematics.kicad_pcb, beer-warmer-schematics.kicad_sch, bom.csv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]
2025-03-30 redid board layout
    [beer-warmer-schematics.kicad_pcb, beer-warmer-schematics.kicad_sch]
2025-03-30 fix screw terminal component
    [beer-warmer-schematics.kicad_pcb, beer-warmer-schematics.kicad_sch, bom.csv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]
2025-03-31 cleanup, update positioning, mess up routing
    [bom.csv, designators.csv, positions.csv]
2025-03-31 power indicator
    [beer-warmer-schematics.kicad_pcb, beer-warmer-schematics.kicad_sch]
2025-03-31 use more standard components
    [beer-warmer-schematics.kicad_pcb, beer-warmer-schematics.kicad_sch]
2025-03-31 move extra tracks to other layer
    [beer-warmer-schematics.kicad_pcb]
2025-04-01 imperial footprint sizes
    [beer-warmer-schematics.kicad_pcb, beer-warmer-schematics.kicad_sch]
2025-04-01 beefier resistor
    [beer-warmer-schematics.kicad_pcb, beer-warmer-schematics.kicad_sch]
2025-04-02 fix a bunch of potential issues, add current sense
    [beer-warmer-schematics.kicad_pcb, beer-warmer-schematics.kicad_sch]
2025-04-04 middle ground plane, 12v over dedicated tracks to avoid noise
    [beer-warmer-schematics.kicad_pcb, beer-warmer-schematics.kicad_sch]
2025-04-04 use a much simpler usb c component
    [beer-warmer-schematics.kicad_pcb]
2025-04-04 wider traces
    [beer-warmer-schematics.kicad_pcb]
2025-04-07 clean up schematics, correct mosfet orientation
    [beer-warmer-schematics.kicad_pcb, beer-warmer-schematics.kicad_sch]
2025-04-07 led indicator on vbus power
    [beer-warmer-schematics.kicad_pcb, beer-warmer-schematics.kicad_sch]
2025-04-07 remove some vias
    [beer-warmer-schematics.kicad_pcb]
2025-04-07 slightly better decoupling cap placement
    [beer-warmer-schematics.kicad_pcb]
2025-04-08 fix active led, bottom silkscreen
    [beer-warmer-schematics.kicad_pcb, beer-warmer-schematics.kicad_sch]
2025-04-08 incorporated some feedback
    [beer-warmer-schematics.kicad_pcb, beer-warmer-schematics.kicad_sch]
2025-04-08 low side driver
    [beer-warmer-schematics.kicad_pcb, beer-warmer-schematics.kicad_sch]
2025-04-09 different step down
    [beer-warmer-schematics.kicad_pcb, beer-warmer-schematics.kicad_sch]
2025-04-09 routing overhaul
    [beer-warmer-schematics.kicad_pcb, beer-warmer-schematics.kicad_sch]
2025-04-13 active led in parallel with load
    [beer-warmer-schematics.kicad_pcb, beer-warmer-schematics.kicad_sch]
2025-04-13 change diode on buck
    [beer-warmer-schematics.kicad_pcb, beer-warmer-schematics.kicad_sch]
2025-11-26 updated with new knowledge gained
    [beer-warmer-schematics.kicad_pcb, beer-warmer-schematics.kicad_sch]
2025-12-15 updated with learnings after production
    [beer-warmer-schematics.kicad_pcb, beer-warmer-schematics.kicad_sch]
2025-12-15 remove designator on silkscreen
    [beer-warmer-schematics.kicad_pcb]
